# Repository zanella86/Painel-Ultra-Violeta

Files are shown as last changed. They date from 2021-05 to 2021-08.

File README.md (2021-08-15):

# Painel-Ultra-Violeta
Painel de LEDs UV para auxiliar na confecção de Placas de Circuito Impresso (processo fotorresistente) e cura da tinta protetora/isolante.

Características:

-PCI com 200x200(mm);

-36 Leds UV de 5mm: 3,3V 40mA (separados em 25mm entre si);

-12 resistores de 56ohms 1/8W (compatibilidade com 1/4W);

-Alimentação em 12V em uma das opções: Conectores "JST macho" ou "Borner com parafuso";

-Consumo total previsto em 1.44A;

-4 vias passantes para fixação (8mm x 3mm).











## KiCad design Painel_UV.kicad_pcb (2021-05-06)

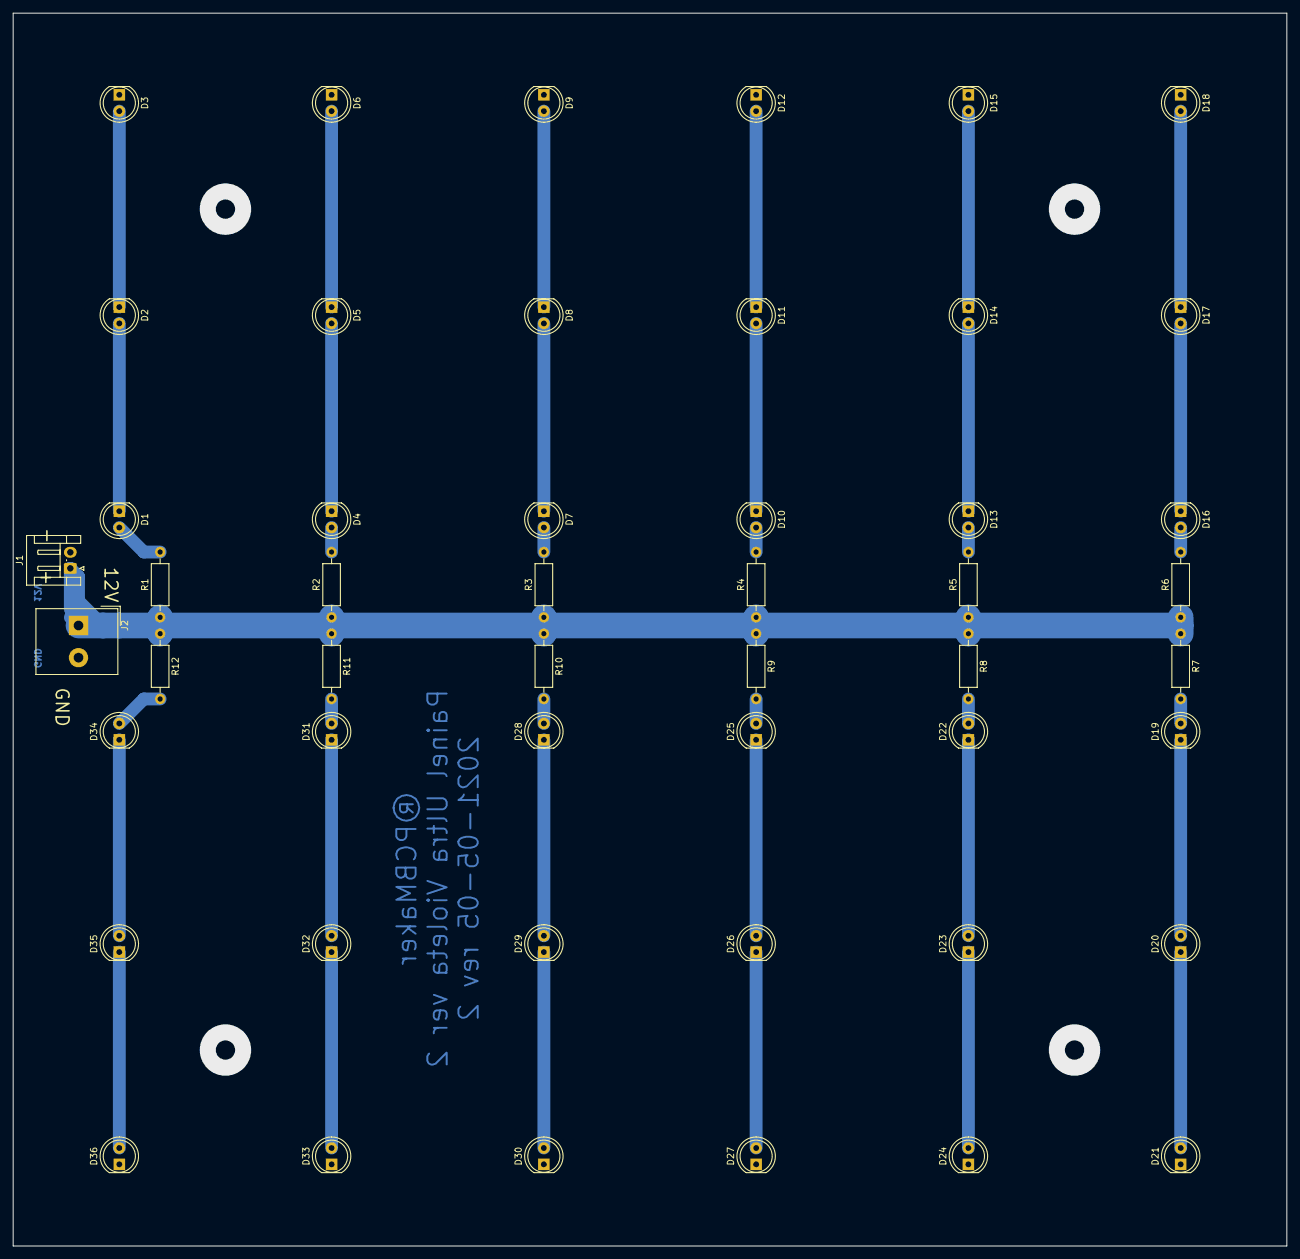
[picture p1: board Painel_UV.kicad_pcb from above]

Board: 2 copper layers, 198.1 x 191.8 mm, 50 parts (0 on the bottom side), 38 nets.

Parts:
D1, D2, D3, D4, D5, D6, D7, D8, D9, D10, D11, D12, D13, D14, D15, D16, D17, D18, D19, D20, D21, D22, D23, D24, D25, D26, D27, D28, D29, D30, D31, D32, D33, D34, D35, D36: LED; LED_D5.0mm
J1: Conn_01x02_Male; JST_EH_S2B-EH_1x02_P2.50mm_Horizontal
J2: Screw_Terminal_01x02; Altech_AK300_1x02_P5.00mm_45-Degree
R1, R2, R3, R4, R5, R6, R7, R8, R9, R10, R11, R12: 56; R_Axial_DIN0207_L6.3mm_D2.5mm_P10.16mm_Horizontal

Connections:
/GND: D3.1, D6.1, D9.1, D12.1, D15.1, D18.1, D21.1, D24.1, D27.1, D30.1, D33.1, D36.1, J1.2, J2.2
/VCC: J1.1, J2.1, R1.1, R2.1, R3.1, R4.1, R5.1, R6.1, R7.1, R8.1, R9.1, R10.1, R11.1, R12.1
unnamed: D1.1, D2.2
unnamed: D1.2, R1.2
unnamed: D2.1, D3.2
unnamed: D4.1, D5.2
unnamed: D4.2, R2.2
unnamed: D5.1, D6.2
unnamed: D7.1, D8.2
unnamed: D7.2, R3.2
unnamed: D8.1, D9.2
unnamed: D10.1, D11.2
unnamed: D10.2, R4.2
unnamed: D11.1, D12.2
unnamed: D13.1, D14.2
unnamed: D13.2, R5.2
unnamed: D14.1, D15.2
unnamed: D16.1, D17.2
unnamed: D16.2, R6.2
unnamed: D17.1, D18.2
unnamed: D19.1, D20.2
unnamed: D19.2, R7.2
unnamed: D20.1, D21.2
unnamed: D22.1, D23.2
unnamed: D22.2, R8.2
unnamed: D23.1, D24.2
unnamed: D25.1, D26.2
unnamed: D25.2, R9.2
unnamed: D26.1, D27.2
unnamed: D28.1, D29.2
unnamed: D28.2, R10.2
unnamed: D29.1, D30.2
unnamed: D31.1, D32.2
unnamed: D31.2, R11.2
unnamed: D32.1, D33.2
unnamed: D34.1, D35.2
unnamed: D34.2, R12.2
unnamed: D35.1, D36.2

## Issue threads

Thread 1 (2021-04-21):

Qual é o método de alimentação mais adequado?

zanella86, 2021-04-21:
Realizar os cálculos para os cenários:

- [x] Alimentação DC em 12V
- [ ] Alimentação AC em 110V

zanella86, 2021-08-15:
Foi desconsiderada à alimentação do circuito em (110VAC), dado que para todas as outras interfaces utilizarão de alimentação DC (5V/12V).

Closed 2021-08-15.

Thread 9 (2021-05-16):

Consumo total estimado incorreto

zanella86, 2021-05-16:
Inicialmente foi estimado o consumo de 1,44A, porém, os LED foram divididos em 12 grupos com 3 LEDs cada. Considerando 40mA por grupo, o consumo correto seria de 480mA.

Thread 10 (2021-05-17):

Furação para fixação insuficiente

zanella86, 2021-05-17:
O tamanho da via em 3mm e furo de 1mm não é suficiente.
Os valores corretos seriam via de 8mm e furação de 3mm.

zanella86, 2021-08-15:
Ajuste realizado na rev 2.

Closed 2021-08-15.

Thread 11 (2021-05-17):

Incluir furação para alimentação via fios

zanella86, 2021-05-17:
Avaliar a inclusão da furação para soldagem dos fios de alimentação.

zanella86, 2021-08-15:
Já existem dois conectores distintos para alimentação. O conector J2 possui furação com diâmetro suficiente (1,5mm) para fixação de fios.

Closed 2021-08-15.

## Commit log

2021-05-05 Update README.md
    Inclusão de imagens do modelo em 3D.
2021-05-06 Esquema elétrico do Painel UV utilizando o método de alimentação DC em 12V (conforme descrito em #1)
    [Painel_UV.sch]
2021-05-06 (#3) Painel desenvolvido em 200x200(mm) com espaço de 25mm entre os LEDS
    [Painel_UV.kicad_pcb]
2021-05-09 #7 e #8: Gerada a lista de materiais utilizando o plugin bom2grouped_csv
    [Painel_UV.sch]
2021-08-15 Update README.md
    Incluído as medidas dos furos passantes e dos LEDs.
